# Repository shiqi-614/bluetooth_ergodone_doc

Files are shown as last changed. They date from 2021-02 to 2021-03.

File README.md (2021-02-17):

# bluetooth ergodone doc

系列文章, 分享如何制作一个蓝牙版的ergodone

由于众所周知的原因, github上的图片不能访问, 可以把本项目下载到本地, 然后用markdown编辑器打开.

或者移步我在CSDN上的博客[地址](https://blog.csdn.net/shiqi_614/article/details/113758502)

改造流程参考教程:
* [为什么要自己做一把蓝牙机械键盘](./chapter1_cn.md)
* [用到的东西](./chapter2_cn.md)
* [制作左手](./chapter3_cn.md)
* [设置左右手蓝牙BLE](./chapter4_cn.md)
* [制作右手](./chapter5_cn.md)
* [轴体焊接及供电模块](./chapter6_cn.md)
* [后记](./chapter_tips_cn.md)

代码地址: [bluetooth_ergodone](https://github.com/shiqi-614/bluetooth_ergodone)

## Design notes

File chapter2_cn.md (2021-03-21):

# 用到的东西

## 系列文章列表
* [为什么要自己做一把蓝牙机械键盘](./chapter1_cn.md)
* [用到的东西](./chapter2_cn.md)
* [制作左手](./chapter3_cn.md)
* [设置左右手蓝牙BLE](./chapter4_cn.md)
* [制作右手](./chapter5_cn.md)
* [轴体焊接及供电模块](./chapter6_cn.md)
* [后记](./chapter_tips_cn.md)

## 硬件相关
#### 焊接工具
* **电烙铁**
* **烙铁架**
* **高温海绵**: 在水中充分浸泡, 挤干后放置在烙铁架
* **焊锡**
* **松香**: 助焊剂, 焊出来的点比较亮, 不容易虚焊
* **吸锡枪**: 如果焊坏了, 将焊点的焊锡吸走, 重新焊
* **电工黑胶带**: 有时候用胶带辅助固定比较好焊
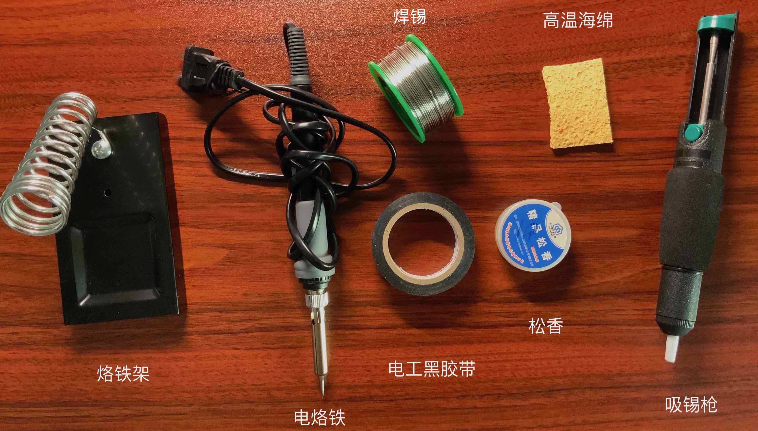
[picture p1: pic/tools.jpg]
焊接工具


#### PCB板等
* **PCB板**: github上有PCB图纸[ErgoDone](https://github.com/shiqi-614/ErgoDone), 需要找淘宝店打印, 用软件[kicad](https://kicad.org/)打开具体的文件查看PCB图纸
* **1n4148二极管 * 76**: 规定电路板上电流的走向, 避免按一个键, 电流走到其他路径, 导致其他按键也认为被触发了, 可以多买些.
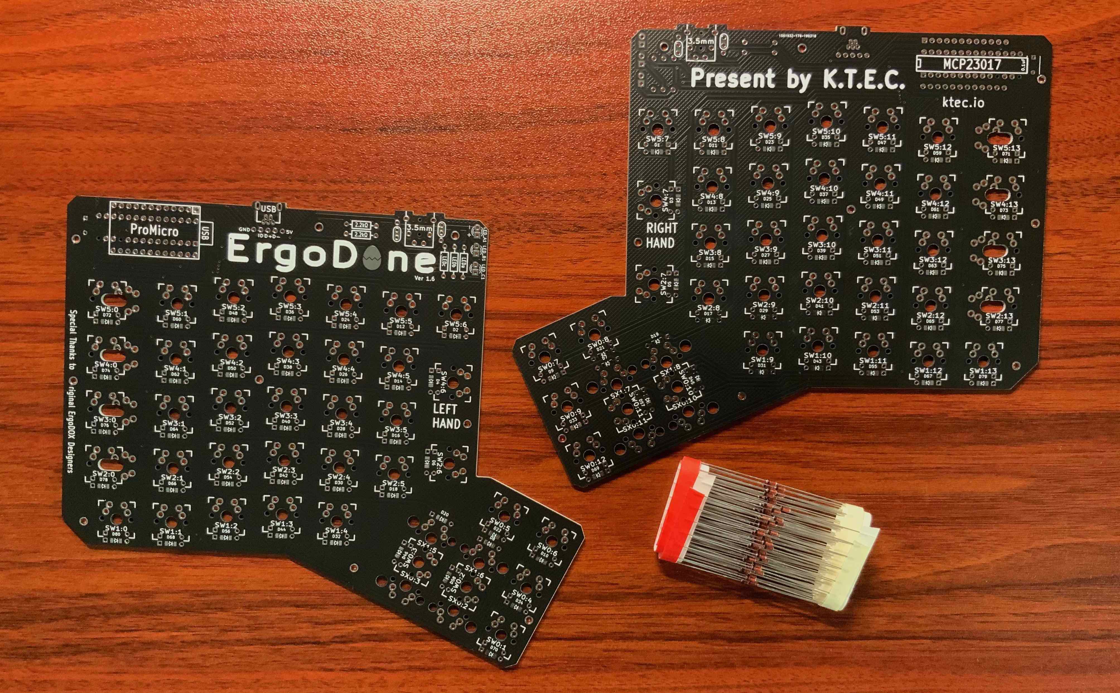
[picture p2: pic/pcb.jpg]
PCB


### 键盘轴体键帽等
* **喜欢的轴休 * 76**: 比如我这里大部分是茶轴, 几个是青轴
* **键帽**: 4个2U的, 12个1.5U的, 60个1U的, 这里我用的白色无刻的
* **PCB卫星轴2U * 4**: 在焊轴前, 安装和调试好卫星轴
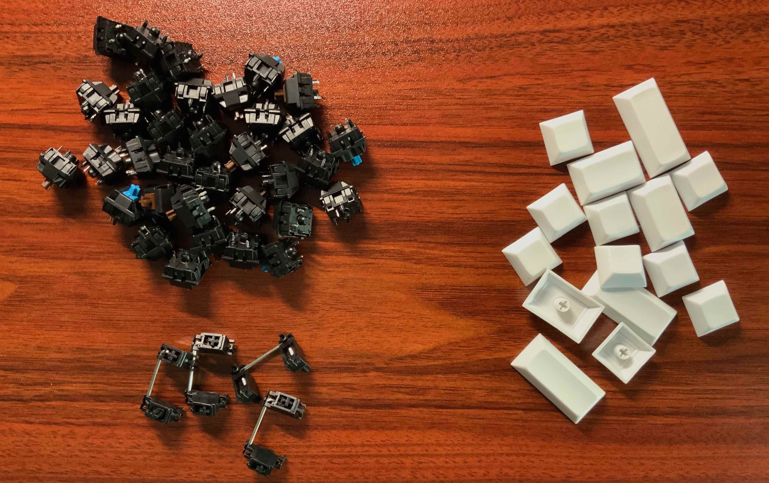
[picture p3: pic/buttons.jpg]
轴体等


### 芯片等
* **Arduino Pro Micro * 2**: 左右手各一块, 主控芯片, 其他名字有min leonardo, ATMEGA32u4. 从淘宝上买, 一般会送直脚排针
* **MCP23017**: IO扩展模块，因为右手需要接入多块芯片或模组及处理键盘事件, 导致IO口不够, 所以用这个来扩展IO口. 使用说明[datasheet](https://pdf1.alldatasheetcn.com/datasheet-pdf/download/195324/MICROCHIP/MCP23017.html), 需要配合2.2K欧的电阻使用.
* **2.2K欧色环电阻 * 2**: 配合MCP23017使用
* **HM-10带底板 * 2**: 左手的Arduino Pro Micro将识别出来的按键事件发送给左手的HM-10, 然后左手的HM-10通过蓝牙将事件发送给右手的HM-10, 右手的HM-10发送给Arduino Pro Micro, 然后发送Bluetooth HID模组
* **Bluetooth HID模组**: HC-03带底板, 这里用的HC-03刷上RN42的固件, 用来给电脑发送鼠标键盘事件, 可以自己制作, 参考[教程](https://mitxela.com/projects/bluetooth_hid_gamepad), 也可以直接从淘宝上买
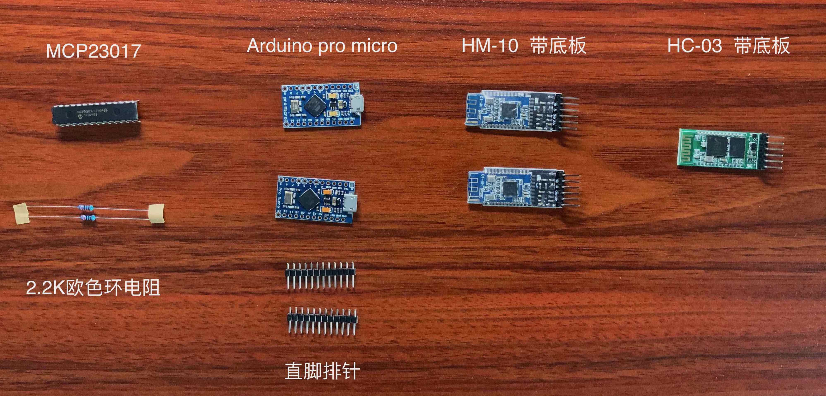
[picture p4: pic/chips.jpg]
芯片等


### 电源模块相关
* **锂电池 * 2**: 用来给芯片供电, 厚度不要超过6mm, 这里我选了一个厚度6mm, 宽度6mm, 长度10mm, 5000mAh, 并且带保护板的电池
* **TP4056充电模块 * 2**: 用来给锂电池充电, 我选的type c口的
* **拨动开关 * 2**: SS12D10, 用来控制电源的开关
* **易拉胶 * 2**: 用来固定电池, 使用易拉胶可以方便以后更换电池, 这里我用是苹果6P的易拉胶
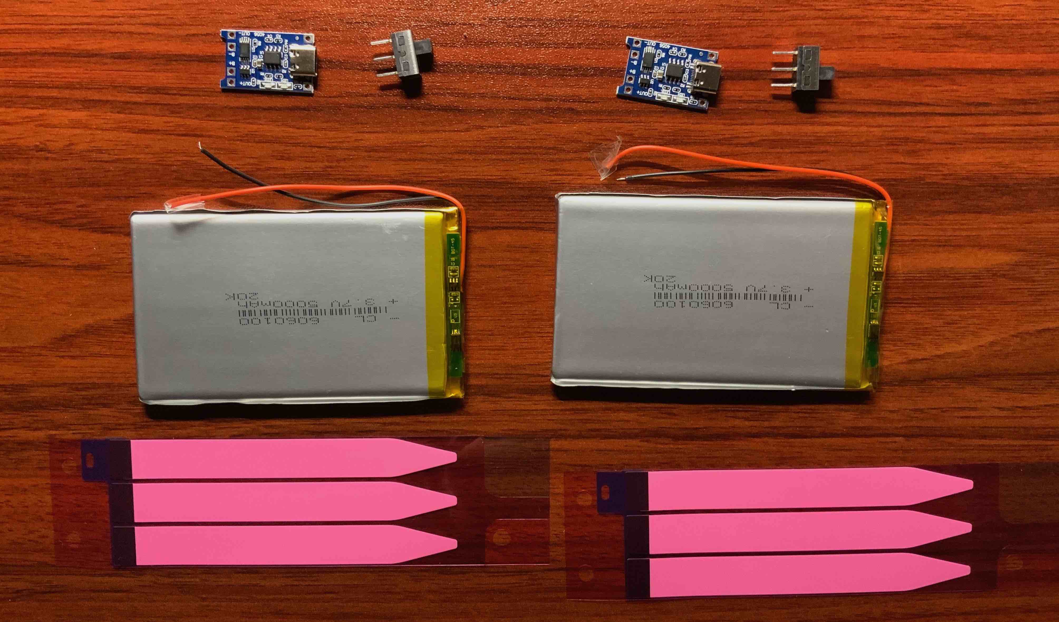
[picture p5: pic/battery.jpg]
电源模块


### 外壳等
* **亚克力外壳**: 我在键盘上加了摇杆, 这是可选的, 如果不想要摇杆, 可以使用这个[不带摇杆的CAD图纸](./cad/Bluetooth_Ergodone_without_joystick.dwg),  如果你也想加上摇杆, 用这个[带摇杆的CAD图纸](./cad/Bluetooth_ErgoDone_with_joystick.dwg), 材料是亚克力, 同样需要找淘宝店加工, 费用大概在120元左右. 可以用AutoCAD打开并编辑这样的文件, 新用户有30天试用, 还是比较方便的. 把膜撕了之后, 就是右手透明的样子, 很好看.
* **M2双通铜柱19MM * 14**: 用来固定外壳
* **M2螺丝8MM * 28**: 用来固定外壳
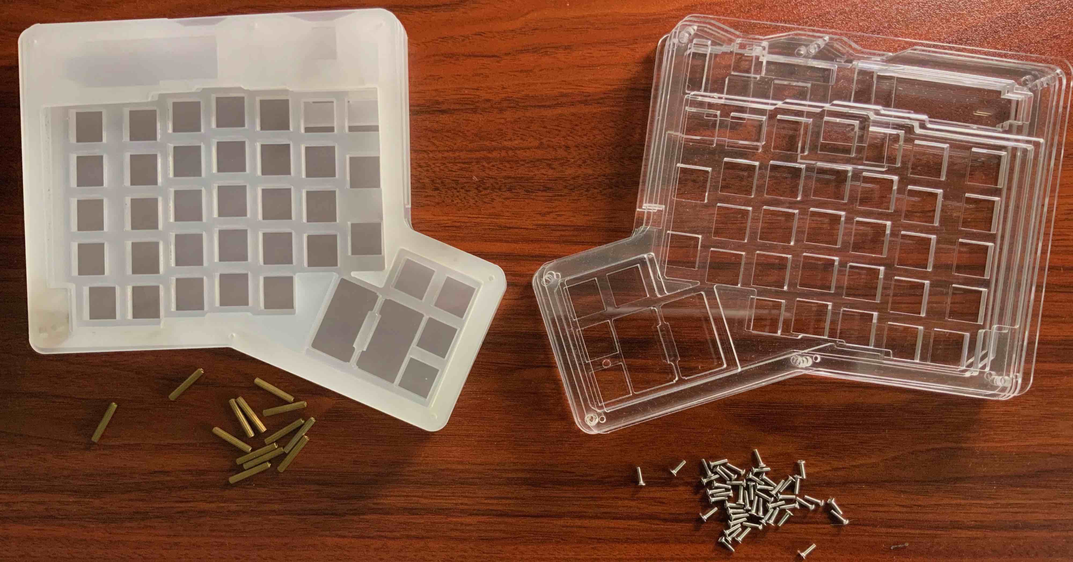
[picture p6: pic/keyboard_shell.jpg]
外壳等


####  连接线
* **弯脚排针**: 为了避免直接用跳线焊接到芯片或者模组的引脚上, 先焊接上排针, 然后用杜邦线连接, 方便以后更换芯片, 如果觉得不牢靠, 可以用黑胶布再固定一下
* **母对母杜邦线**: 用来连接芯片模组和PCB等. 我用到了10CM, 15CM 20CM三种长度的. 当然也可以直接用跳线焊死, 就不用上面的弯脚排针了. 可以买一个公对公的杜邦线, 在没有焊上轴之前, 当成导线测试二极管焊得对不对.
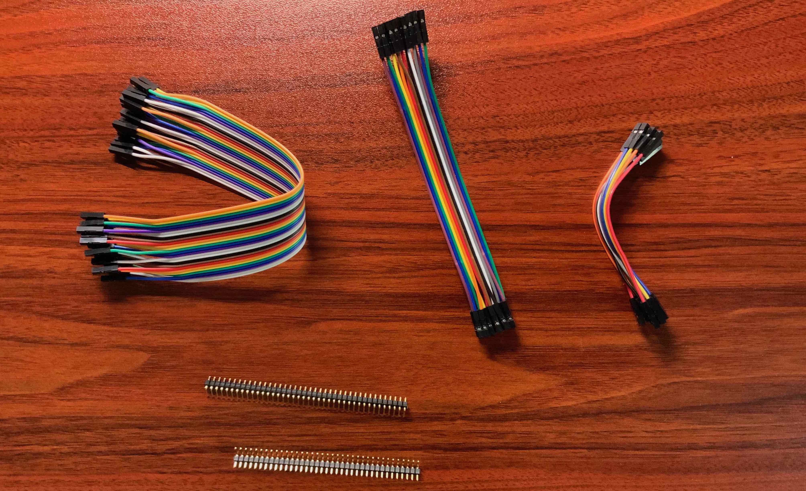
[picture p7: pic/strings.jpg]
连接线


### 其他
* **USB转Micro USB * 2**: 在测试的时候, 同时给两块Arduino Pro Micro供电需要用到, 也用来给芯片烧录程序, 所以要买那种支持数据传输的.
* **330欧色环电阻 * 3**: 避免电流过大烧坏LED灯.
* **234 LED方灯 * 3**: 放在键盘上, 可以用来提示CAPS_LOCK, 或者自定义提醒键盘布局变化.
* **纳米双面胶**: 用来固定芯片或者模组, 粘在外壳上

### 可选
* **摇杆**: 用来控制鼠标, 类似于thinkpad上的小红点
* **小红帽**: 因为上面的摇杆自带的摇杆帽太高了, 使用起来不舒服,所以用thinkpad小红点上的小红帽替代, 也可以先试试原装的蘑菇帽, 觉得不行了, 再换成小红帽试试(可惜没有矮点的蘑菇帽, 原装的蘑菇帽手感非常 好), 不是成熟的方案, 我自己也不满意, 如果有更好的方案, 请指教.
* **502胶水**: 因为小红帽和摇杆不匹配, 塞了点东西, 用脱水粘上
* **隐形笔记本支架**: 让键盘有一个比较舒服的角度
* **鼠标垫**: 因为加了一块电池的键盘太厚了, 所以加了鼠标垫拖着手, 一手一块不够厚, 所以一手两块
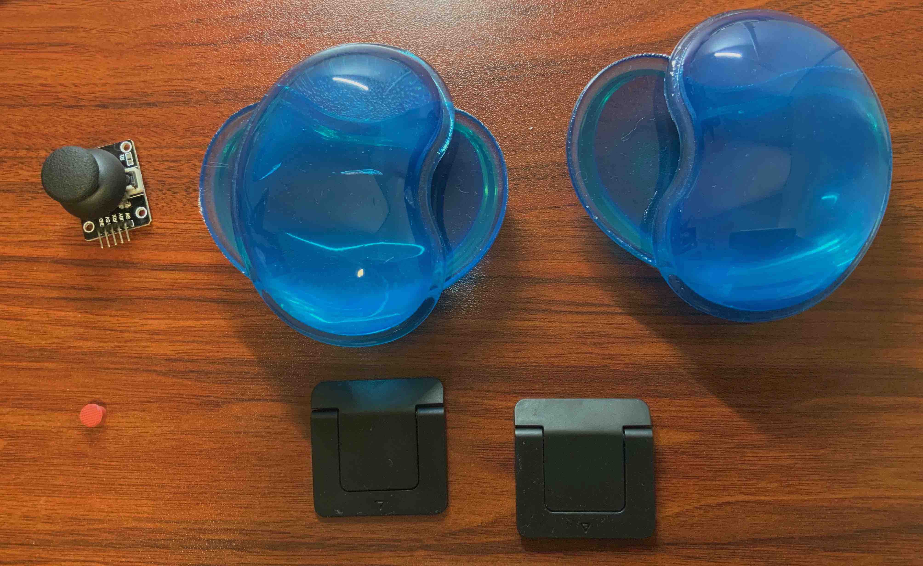
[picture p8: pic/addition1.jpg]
addition1

* **阳极铝定位板**: 我在使用中摔过一次, 定位板碎了, 因为定位板是和PCB板焊在一起的, 更换起来很麻烦,  所以这次用了金属材料, 阳极氧化铝, 如果你也需要, 可以用这个[定位板的图纸](./cad/positioning_plate.dwg), 其他不变.
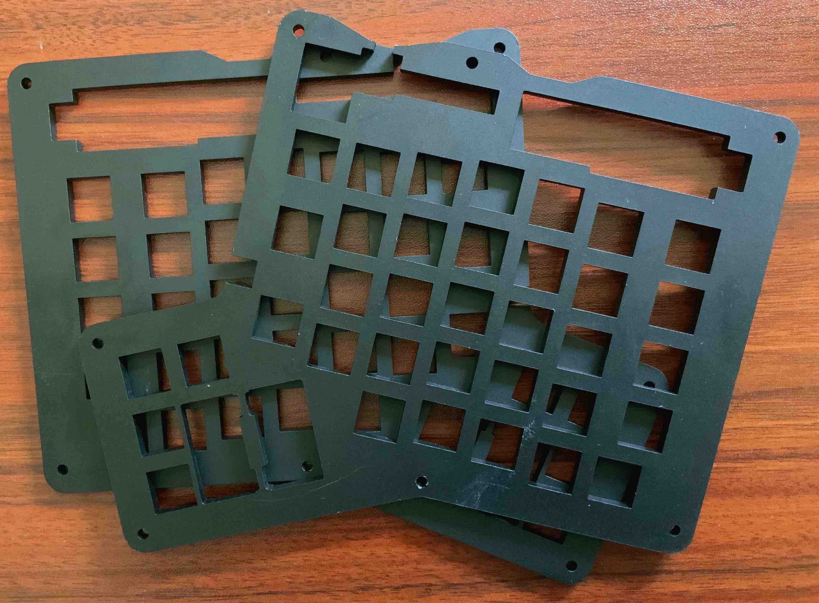
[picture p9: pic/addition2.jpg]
addition2


## 软件相关
使用了[Arduino IDE](https://www.arduino.cc/en/software), 基于[arduino_tmk_keyboard](https://github.com/bgould/arduino_tmk_keyboard).

代码使用方法是: 从Release里下载[bluetooth_ergodone.zip](https://github.com/shiqi-614/bluetooth_ergodone/releases/download/1.0/bluetooth_ergodone.zip), 在Arduino IDE里, 通过"项目" -> "加载库" -> "添加.zip库", 把本项目导入.

导入完成后, 还需要
1. **选择正确的示例程序**: 在Arduino IDE里, 通过"文件" -> "示例", 找到本项目名, 然后打开左手或者右手的示例程序,
2. **选择正确的开发板**: 在Arduino IDE里, 通过"工具" -> "开发板"里选择Arduino Leonardo,
3. **选择正确的端口**: 当电脑的USB连接到主控芯片(Arduino Pro Micro)后, 在"工具"->"端口"里会出现一个新的端口, 选择这个端口.

然后点Arduino IDE左上角的"上传"按钮, 就可以将代码上传到主控芯片里了.

在右手的示例程序里[right_hand.ino](https://github.com/shiqi-614/bluetooth_ergodone/blob/master/examples/right_hand/right_hand.ino), 可以通过ERGODONE_KEYMAP去定义自己的键盘布局, 支持多个键盘布局的切换, 比如我定义了三层, 第三层是鼠标的操作. 还可以自己定义一些宏操作, 比如在第二层里自定义了FN6, 按下这个键, 就会输出Hello, World. 更多玩法, 参考[tmk keymap](https://github.com/tmk/tmk_keyboard/blob/master/tmk_core/doc/keymap.md).

并且也是在右手的程序里[right_hand.ino](https://github.com/shiqi-614/bluetooth_ergodone/blob/master/examples/right_hand/right_hand.ino)通过各种hook函数控制LED灯.

我自己定义键盘布局里, 左手CAPS_LOCK按键的位置被我换了, 按成按着的时候, 会切换到第三层, 第三层是鼠标操作, 在第三层, 按下HJKL会移动鼠标. 原来Z键的位置, 被我换成按下切换到第二层, 这时候HJKL就变成方向键, 原来的Z向右移了一位.

# 最后的成品
### 正面
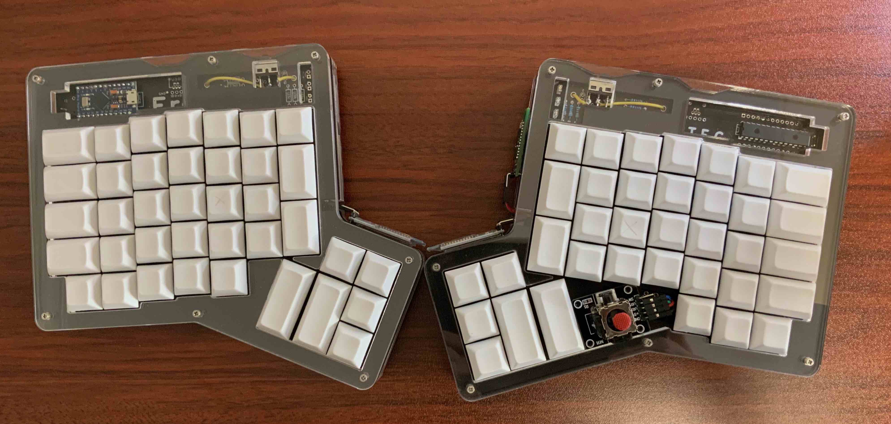
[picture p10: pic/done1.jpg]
done1


### 背面
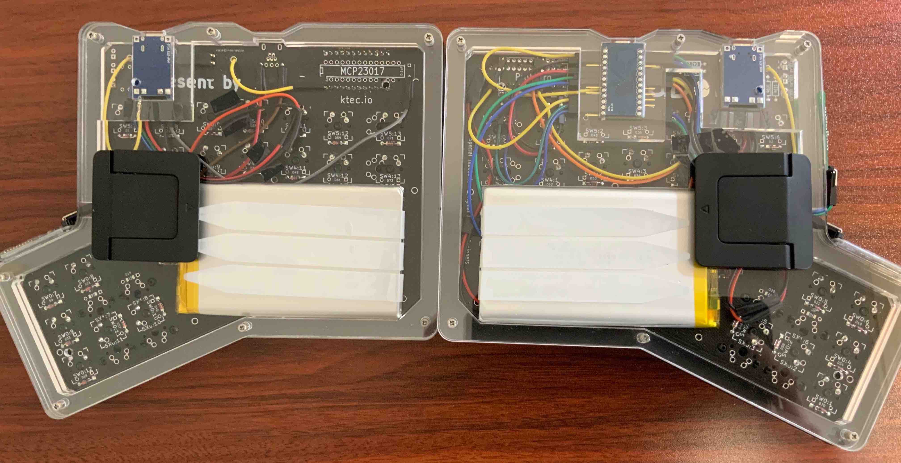
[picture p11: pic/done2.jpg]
done2


### 侧面
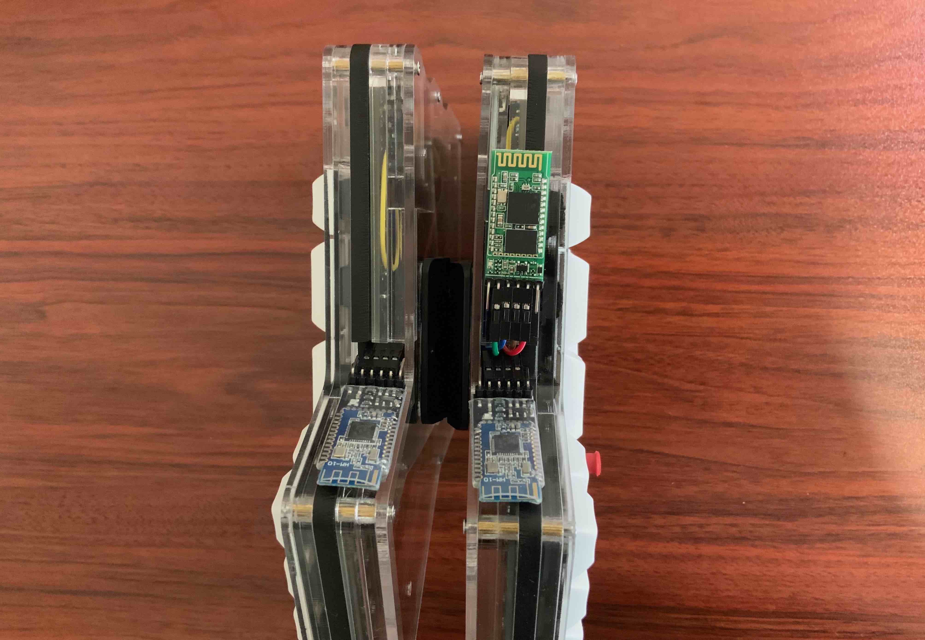
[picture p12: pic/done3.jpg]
done3


### 用起来的样子 
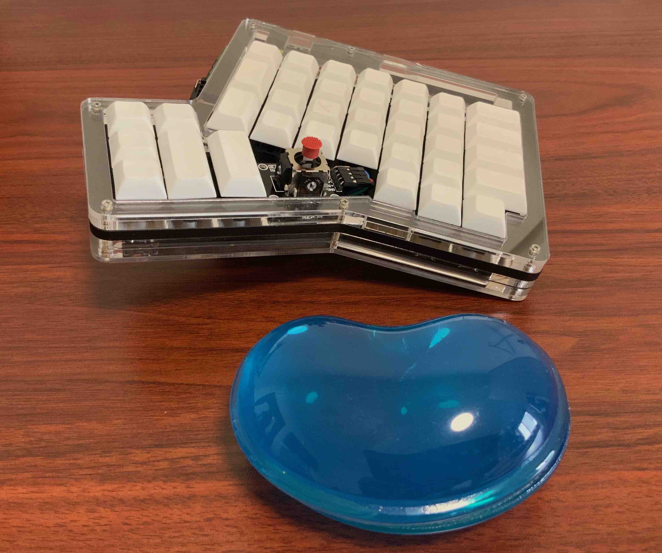
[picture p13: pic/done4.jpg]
done4


续航测试, 右手大概在360个小时之后, 开始出现连接不稳定, 左手这时候还能继续用, 左手没有继续测试下去.

测试过的能连接上的设备包括Mac电脑, windows电脑, ipad, iphone, 小米6.

延迟测试, 不会有明显的延迟, 尝试使用程序测试, 左手某个按键按下, 从Arudino打印的时间, 对比电脑上python监测程序打印出来的时间, 三四十毫秒到八九十毫秒都有. 不过应该是大概二十毫秒, 考虑到蓝牙传输的延迟(七点五毫秒发送一次按键事件, 这里乘以二, 因为有两个), 程序里去抖动延迟五毫秒(由于机械轴触发的原理是两个弹片互相接触, 机械接触的话难以避免碰撞, 又因为程序检测的速度极快, 所以这段极小的碰撞时间内程序检测到的状态是不稳定的, 会被认为是按下松开按键多次). 网上有人用拍视频的方式计算, 用视频里按下按键的帧数到屏幕显示出来的帧数, 计算出对应的时间. 比较麻烦, 放弃.

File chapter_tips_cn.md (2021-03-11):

# 后记

## 系列文章列表
* [为什么要自己做一把蓝牙机械键盘](./chapter1_cn.md)
* [用到的东西](./chapter2_cn.md)
* [制作左手](./chapter3_cn.md)
* [设置左右手蓝牙BLE](./chapter4_cn.md)
* [制作右手](./chapter5_cn.md)
* [轴体焊接及供电模块](./chapter6_cn.md)
* [后记](./chapter_tips_cn.md)

### 一些想法
* 我觉得外壳的分层的设计挺好的, 可以单独对某些层做特别的定制, 除了成本方面的考虑之外, 比如对右手有装摇杆需求的, 就可以仅向右手上面两层做一些修改, 使得摇杆能够放下. 那么可以更进一步, 除了PCB板和定位板是焊死的 (这块拆起来比较麻烦, 需要用吸锡器清理38个焊点), 在现在的设计里, 所有的连线都没有焊死, 用的是杜邦线进行连接, 意味着如果你想用其他的充电模块, 你可以把对应充电模块的那一层, 包括芯片模组和外壳整体替换掉, 而其他层保持不变, 这为以后维护升级提供了许多便利.
* 一开始我想着, 可以让左右手互相通信, 但是后来放弃了这个想法, 沿用了类似于HM-10的主从模式, 因为如果左右手需要通信才可以完成一些事件, 意味着单独右手不能成为一个独立的键盘, 需要和某个左手绑定, 这我认为是没有必要的, 并且如果遵守蓝牙BLE的协议, 左手其实可以是其他的设备, 并不一定要是键盘, 可以玩出更多花样.
* Bluetooth HID模组本来想用RN42的, 但是成本太高了, 裸片都要100多块(我焊不上去, 放弃), 带上底板了直接上300多块钱了, 而淘宝上用HC-03刷RN42固件的, 加上运费也只需要30多, 两者价格相差10倍, 试错成本太高了, 导致放弃了这个方案. 
* Bluetooth HID模组后来还尝试过ESP-32, 这块芯片集成了蓝牙和无线, 通过阅读了蓝牙HID协议, 把github上用ESP-32分别操作键盘和鼠标的合在一起, 但是ESP-32太娇贵了(一块50多, 官方淘宝店运费23), 我在续航测试中, 测到没电, 再供电时, 蓝牙就无法连接了, 再加上其他问题(体积太大, 续航等), 导致我也放弃了这个方案. 所以Bluetooth HID这块, 用的现在的方案. 这个方案不能对代码进行一些定制, 导致有些功能, 比如鼠标滚轮左右滚, 如同罗技K380那样, 一键切换多台设备, 不能实现.
* 代码方面, 固件QMK比TMK功能更强大, 并且也更流行一些, 但是刷QMK的固件更麻烦一些, 需要额外的知识, 而用Arduino IDE对小白来说更友好, 在界面上点一下"上传"就搞定了(其实这个过程有把代码输出成HEX格式的文件, 再烧录到芯片里), 并且在网上找到了将TMK移植到Arduino上的项目(即arduino_tmk_keyboard), 所以最终采用了TMK, 因为arduino_tmk_keyboard里使用的TMK版本有点老, 有挺多bug, 所以最后折腾了一阵, 升级到当前最新版的TMK, 除了升级, 适配新的硬件, 还在主程序里增加了一些hook的接口, 我是用hook的接口还实现led的控制.
* 现在并没有休眠功能, 因为正常用下来, 右手一个月左右充一次电, 左手时间更长, 对我来说, 是能接受的.
* 想实现像罗技K380的一键切换多个设备的功能 (比如你有电脑和IPAD, 上班的时候键盘上的蓝牙连接的是电脑, 下班之后, 按下键盘上的一个按键, 键盘上的蓝牙就连接上IPAD的了, 明天上班了, 按下另一个按键上的蓝牙就连接上电脑了), 这得对蓝牙HID模组的固件进行定制, 找到开源项目[cc254x-hidKbdM](https://github.com/rampadc/cc254x-hidKbdM), 对应的烧录的教程在[这里](https://www.cyqsd.cn/8498.html), 完成这个功能需要大量时间, 有时间再弄.

### 踩过的坑
* 有些micro USB线仅支持充电, 用这种线, 是识别不出芯片的, 要买那种还支持数据传输的.
* 淘宝上有许多HM10, 最好去官网的淘宝店买, 因为需要配置主从模式, 其他淘宝店上的命令和官网有点不一样, 有时候弄不成功, 淘宝客服找了技术支持, 把我自己的linux系统装了windows系统, 买了USB转TTL的线从windows上连接, 折腾好一阵, 还是不行, 所以找官网的淘宝店买最好, 不过官网的淘宝店运费真的贵.
* HM-10左右手虽然连接上了, 但是左手给右手发的数据老是接不到, 后来把右手的HM-10上的TX和RX与Arduino Pro Micro的RX和TX连接, 才能收到数据. 其他引脚是用的模拟串口通信, Arduini Pro Micro上的TX和RX引脚是硬件支持串口通信的. 后来并没有用官方淘宝店的HM-10做实验, 也不知道是哪里的问题.
* 用过ESP32-DevKitC作为蓝牙HID ,  我做续航测试的时候, 电池电量消耗完之后, ESP32的蓝牙功能就出问题了, 然后因为ESP32上面的软件也是我写的, 虽然是蓝牙4.0, 不过没有休眠之类的功能, 导致续航比较低(只有50个小时), 然后ESP32-DevKitC也比较大, 之前从非官网的淘宝店买, 还出现过, 引脚标错的情况, 折腾了许久.
* 用过黑莓的轨迹球去控制鼠标, 这个模组很小, 不过不能同时识别两个方向, 所以往右上移动, 只能先往右移动, 再往上移动, 所以体验不是很好, 虽然我用软件尝试去解决, 但是效果也不好.
* 单独找了淘宝店做阳极铝的定位板, 但是在开关位置, 精度有点问题, 用的开关宽是12.7MM, 长是13.2(不包括拨动的那一部分), 图纸里标了宽12.77MM, 长度是13.4MM, 但是楞是卡不进去, 最后使用把定位板对应的位置刮了刮, 把开关的脚剪掉一部分, 才能用力锤进去的, 原来亚克力的版本就能顺利卡进去.
* 用阳极铝定位板, 如果PCB上的二极管的焊点太突出了, 会导致电流走到定位板上, 导致一些奇怪的现象, 所以这时候要用黑胶布把焊点盖一下.

我在B站上上传了一个之前0.1版本的制作过程的视频, https://www.bilibili.com/video/BV1qv411y7vA, 不知道会有多少人看到这里, 如果你看到了这里, 可以去给这个视频点个赞或者投个币, 一起看看结果.

### 参考资料

#### B站：
* 10天学会51单片机—郭天祥
* CAD2018新手快速入门精品课

#### 文档书籍：
* 从零开始学单片机技术
* Arduino基础入门
* 普及版ErgoDox——ErgoDone二狗蛋人体工学
* 正式版Ergodone二狗蛋教程(群友分享)
* datasheet of ESP32
* datasheet of MCP23017
* datasheet of HM10

#### github:
* bgould/arduino_tmk_keyboard
* tmk/tmk_keyboard
* LSChyi/BlueErgo_Protype
* T-vK/ESP32-BLE-Keyboard
* T-vK/ESP32-BLE-Mouse
* ktec-hq/ErgoDone
* LSChyi/blackberry-mini-trackball

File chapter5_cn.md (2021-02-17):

# 制作右手

## 系列文章列表
* [为什么要自己做一把蓝牙机械键盘](./chapter1_cn.md)
* [用到的东西](./chapter2_cn.md)
* [制作左手](./chapter3_cn.md)
* [设置左右手蓝牙BLE](./chapter4_cn.md)
* [制作右手](./chapter5_cn.md)
* [轴体焊接及供电模块](./chapter6_cn.md)
* [后记](./chapter_tips_cn.md)

在前面的章节里, 我们完成了左手的焊接, BLE的设置, 接下来开始制作右手, 右手会负责接受左手键盘发过来的信息, 摇杆信号的变化, 右手键盘的事件, 控制LED灯, 还负责跟电脑打交道. 可以用下图表示整个键盘各种模块之间的关系.
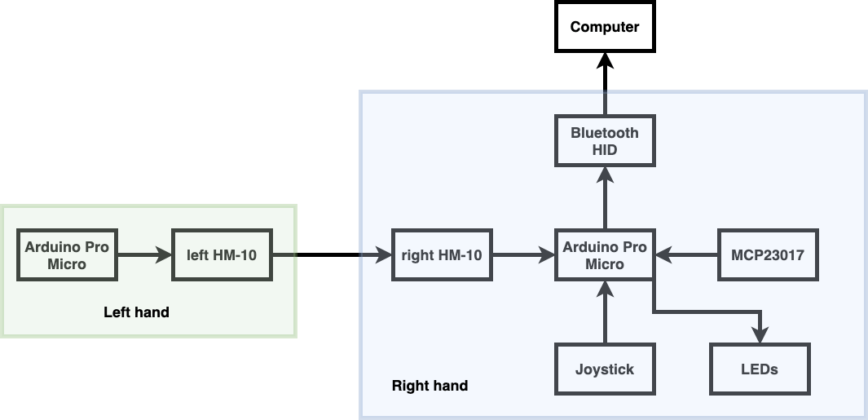
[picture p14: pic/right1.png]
right1


为什么要加一个MCP23017呢?

可以从上图看到, 右手的Arduino Pro Micro要负责的事情很多, 但是IO引脚数目有限, 如果像左手那样, 光监测键盘事件就把IO引脚基本占用完了, 所以用MCP23017去扩展IO引脚, 这个模组可以用2根IO引脚扩展出16根IO引脚, PCB上也给MCP23017预留了位置. 至于原理是什么, 有兴趣可以找一下MCP23017的datasheet, 里面介绍得很详细.

拿出一张PCB板, MCP23017, 按照下图放好, 特别要注意放的方向, 然后焊接上.
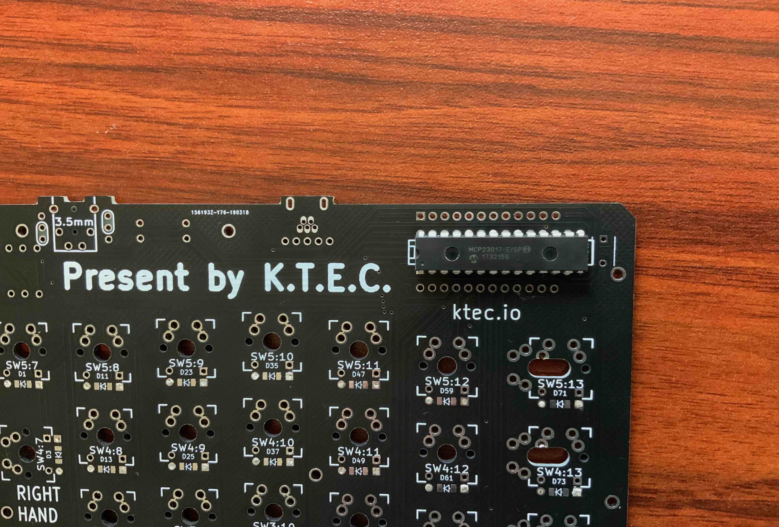
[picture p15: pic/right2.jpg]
right2


接下来把对应位置的电阻也焊接上. 位置1焊接2个2.2K殴的电阻, 位置2焊接3个330欧电阻, 这时候LED灯先不着急焊, 因为如果LED灯方向焊反了, 灯就亮不起来了.
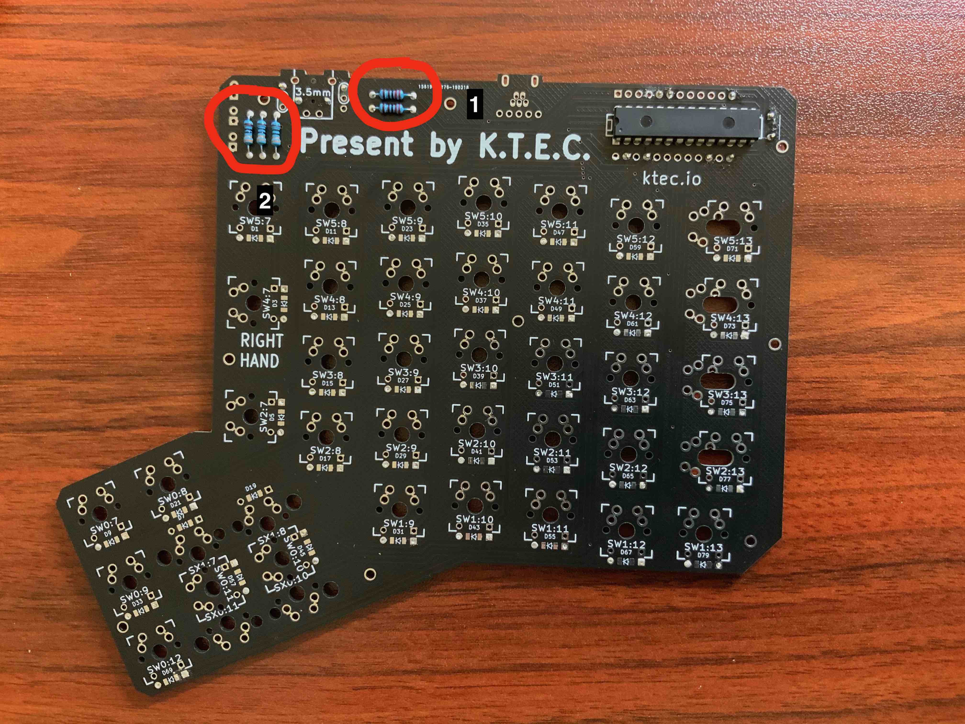
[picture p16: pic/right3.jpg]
right3


然后翻到反面, 把二极管也焊接上, 并且在下面的几个位置也用之前教的方法, 焊上弯脚排针.
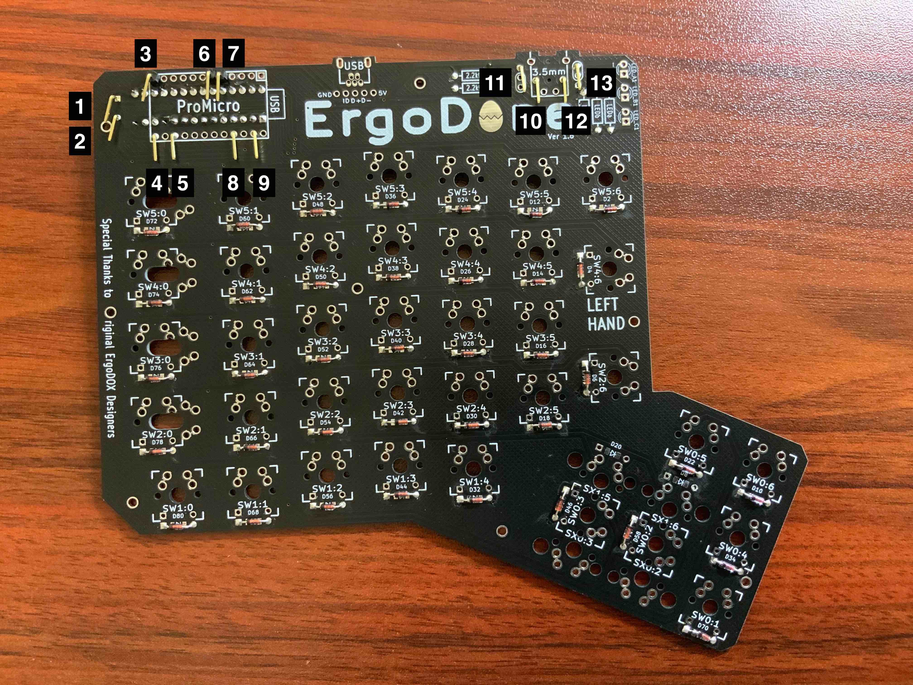
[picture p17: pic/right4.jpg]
right4

可以先把位置3456789连接上, 先测试LED和MCP23017是否正常工作,  完整的连接对应关系如下:

* 1 (VCC)    -> Joystick pin 5V
* 2 (GND)    -> Joystick pin GND
* 3 (LED A)  -> Arduino Pro Micro pin 15
* 4 (LED B)  -> Arduino Pro Micro pin 14
* 5 (LED C)  -> Arduino Pro Micro pin 16
* 6 (SCLM 与MCP23017通信的)  -> Arduino Pro Micro pin 3
* 7 (SDAM 与MCP23017通信的)  -> Arduino Pro Micro pin 2
* 8 (VCC)    -> Arduino Pro Micro pin VCC
* 9 (GND)    -> Arduino Pro Micro pin GND
* 10 (VCC)   -> HM-10 pin VCC
* 11 (GND)   -> HM-10 pin GND
* 12 (VCC)   -> Bluetooth HID pin VCC
* 13 (GND)   -> Bluetooth HID pin GND

另外, 还需要将HM-10, Bluetooth HID, Joystick数据传输的引脚跟Arduino Pro Micro相连, 具体如下:
* HM-10 pin TXD         -> Arduino Pro Micro pin RXD
* HM-10 pin RXD         -> Arduino Pro Micro pin TXD
* Bluetooth HID pin TXD -> Arduino Pro Micro pin 8
* Bluetooth HID pin RXD -> Arduino Pro Micro pin 9
* Joystick pin URX      -> Arduino Pro Micro pin A3
* Joystick pin URY      -> Arduino Pro Micro pin A2
* Joystick pin SW       -> Arduino Pro Micro pin A1

拿出之前焊好的右手的Arduino Pro Micro, 把位置3456789连接好之后, 打开示例, 找到本项目里的"test_mcp23017_led", 上传到Arduino Pro Micro里, 然后我们可以选三个自己觉得好看的LED灯, 放到对应的位置, 看是否能亮起来. 下图所示, 我选了黄色, 蓝色和绿色, 并且LED灯能正确亮起来, 这时候就可以放心地把LED焊上去.
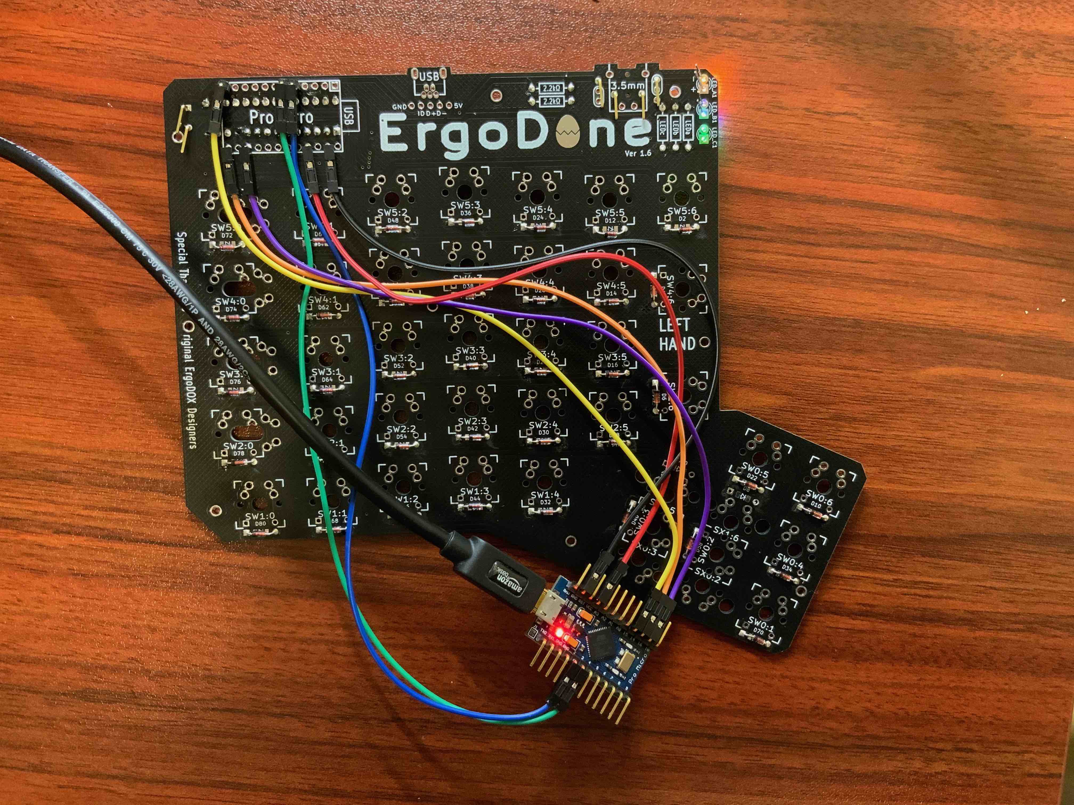
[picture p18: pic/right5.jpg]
right5


这时候, 可以模拟下右手PCB上按键按下的事件. 如果能打印出对应的行和状态(这里是二进制表示), 那么MCP23017的功能也验证成功了.
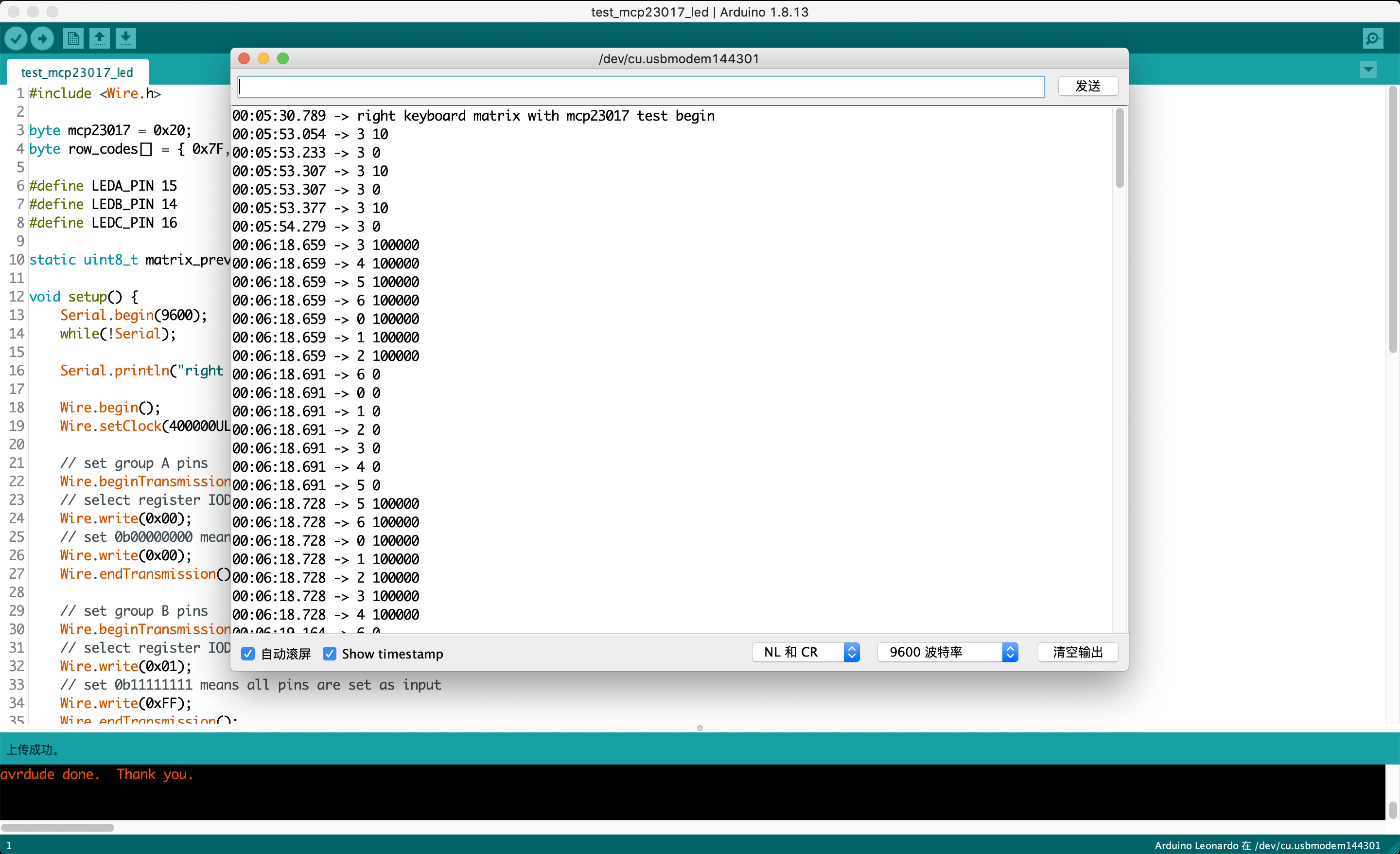
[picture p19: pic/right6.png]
right6


那么现在, 除去充电供电模块外壳等, 你手上已经有一个完整的键盘了, 按照上面的列表, 把所有的连线通过杜邦线连接起来, 并且给左手的Arduino Pro Micro也上电, 这就完成了一个具备所有功能的键盘.

强烈建议这时候去试一下整个键盘的功能, 是否正常, 所有的按键能否正常响应, 摇杆能否正常工作, 之后把外壳等加上去, 检查出问题, 再修复就麻烦一些了.
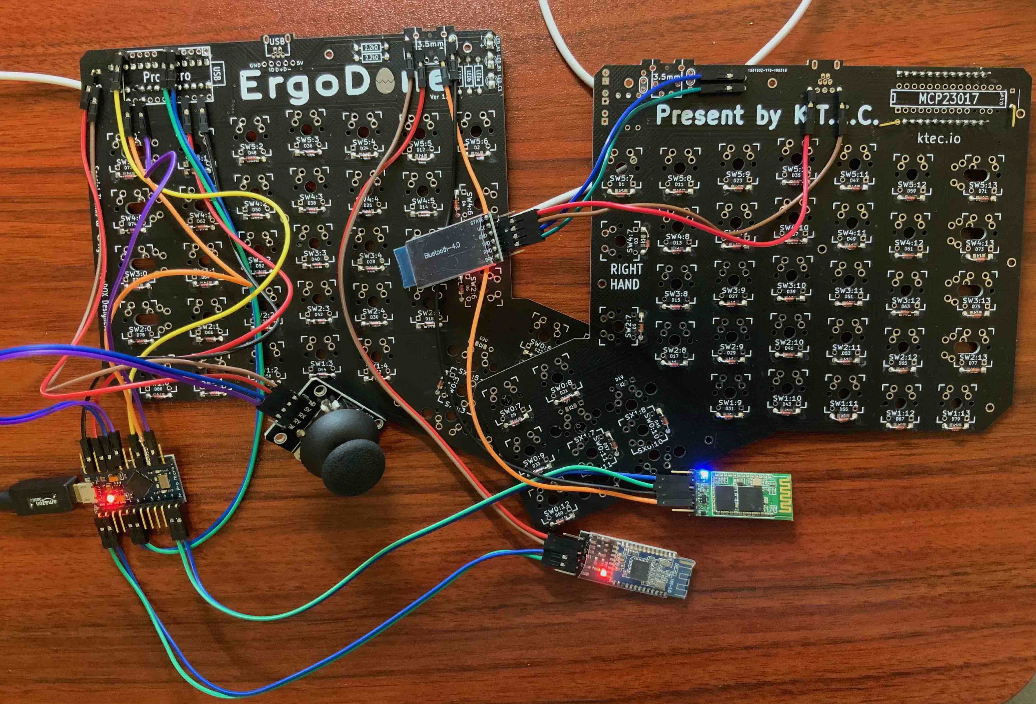
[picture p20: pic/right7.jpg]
right7


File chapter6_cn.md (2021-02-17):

# 轴体焊接及制作供电模块

## 系列文章列表
* [为什么要自己做一把蓝牙机械键盘](./chapter1_cn.md)
* [用到的东西](./chapter2_cn.md)
* [制作左手](./chapter3_cn.md)
* [设置左右手蓝牙BLE](./chapter4_cn.md)
* [制作右手](./chapter5_cn.md)
* [轴体焊接及供电模块](./chapter6_cn.md)
* [后记](./chapter_tips_cn.md)

在前面的章节里, 硬件和软件都验证完成了, 接下来就可以把轴体焊接上去, 把供电模块加上去了.

如果你使用的时阳极铝定位板, 在焊轴之前, 最好把下面的二极管焊接点, 用黑胶布粘上. 避免阳极铝导电, 而造成的奇怪的现象.
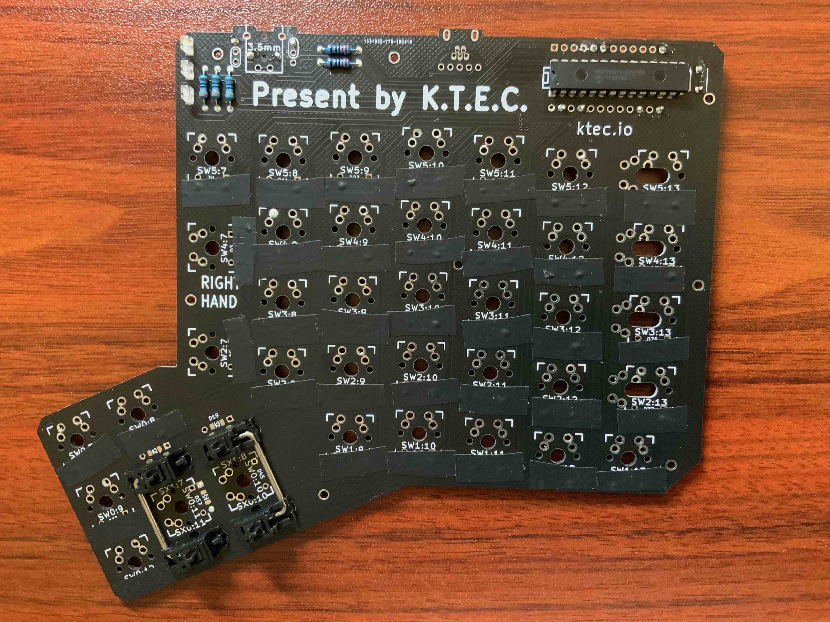
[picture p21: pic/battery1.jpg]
batter1


在焊轴之前, 先把卫星轴安上去, 调试一下, 因为如果没有安装好, 会很影响手感.
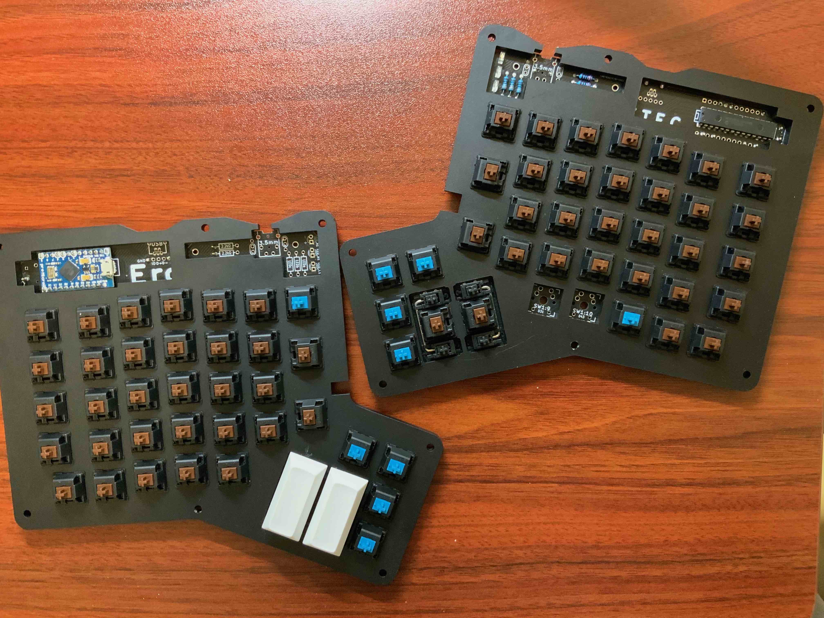
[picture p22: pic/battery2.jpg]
batter2


然后把轴焊上去.
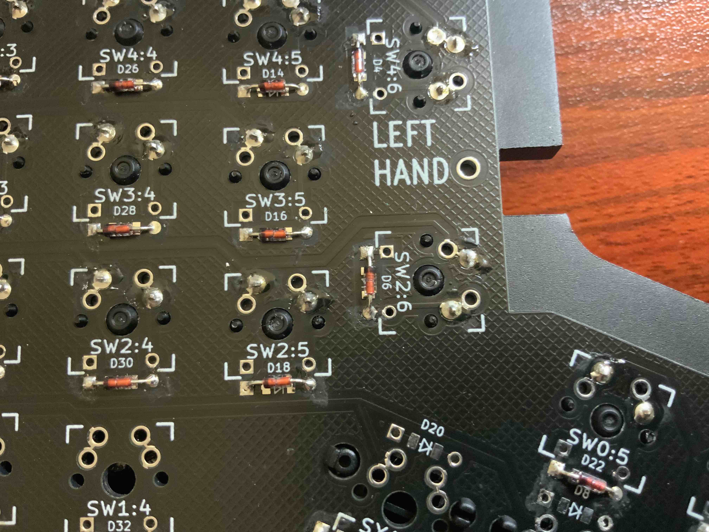
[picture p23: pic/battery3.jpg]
batter3


然后拿出一块TP4056充电模块, 拿出放充电模块的外壳和一个只有边框的外壳. 按照下图的方式放在一起, 然后同样用弯脚排针放进充电模板的引脚里, 用胶布固定在外壳上.
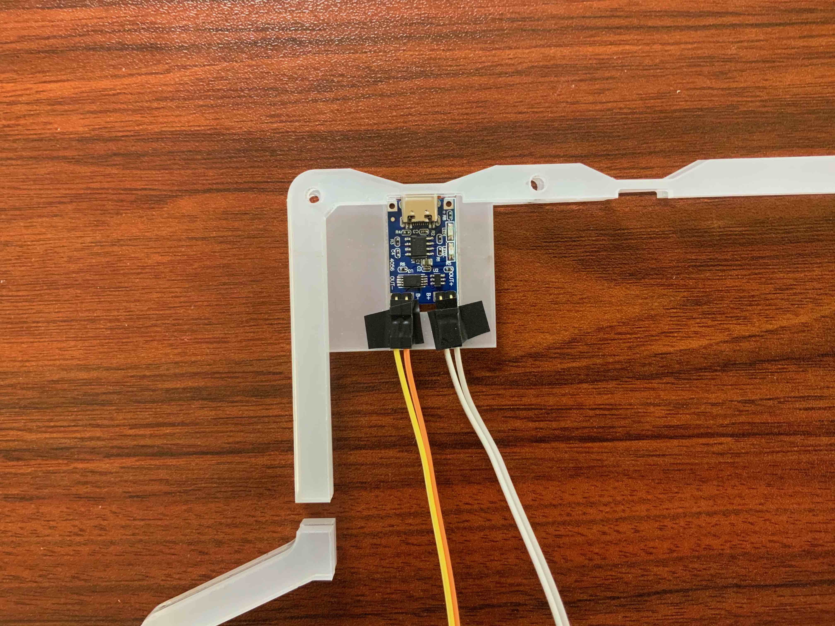
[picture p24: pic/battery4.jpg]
batter4


翻过来, 把充电模块上的弯脚排针焊上. 只有边框的外壳, 是放在PCB板和电池之间, 提供一些空间, 避免直接接触, 也能卡住充电模板, 避免掉下来, 如果不放心, 也可以用黑胶布多固定一下. 焊好之后, 如下图.
batter5

接下来处理锂电池, 拿出一个锂电池, 把它跟杜邦线接在一起, 具体做法是把杜邦线切成两半, 然后把塑料外壳去掉一些, 我是正面划一刀, 背面划一刀, 然后剥开, 锂电池对应红黑线的地方也做相同的处理, 然后把它们缠在一起, 用焊锡加固一下, 再用黑胶布包一下.
batter6
 
拿出一个拨动开关, 同样是把杜邦线一头的塑料外壳去掉一些, 缠到开关相邻的的脚上, 用焊锡固定. 右手的开关的杜邦线弄长一些, 因为右手键盘里的线太多了, 理线比较有发挥空间.
batter7

因为供电模块两手各一组, 所以把两组都处理完.
batter8

然后拿出底下两层外壳, 用铜柱及螺丝固定上, 给电池装上易拉胶(蓝色那一面先撕起来), 放上去, 同时把充电模组也放上去, 线按照下图的方式接上.
batter9

正面装上开关, 这里需要把杜邦线上的塑料头去掉, 才能通过PCB板上的洞, 通过之后, 再把塑料头装上.
batter10

背面这样连接.
batter11

然后组合起来, 把接到拨动开关的另一条线, 接到充电模块的OUT+口. 充电模块的OUT-, 接到PCB板上剩下的弯脚排针上. 左手基本上就完成了, 剩下就是把其他的外壳装上去.
batter12

组装右手的过程, 比较类似, 摇杆我装在下图的位置, 小红点, 不能直接安装到摇杆上, 我是里面塞了点东西, 然后用胶水粘上, 也可以先试试原来摇杆自带的蘑菇帽用得感觉怎么样, 觉得不行再换. 还有, 摇杆模组里的电路极右上角要剪掉一小块, 不然有个按键按不下.
battery_right1

右手的安装过程, 比较类似, 充电模块的OUT-直接用杜邦线连接到Arduino Pro Micro的随便一个GND口. 剩下就是整理线, 让外壳能合上.
battery_right2
上图的位置1和位置2合起来的时候, 会压到一起, 因为位置2是给两组VCC和GND口, 离得比较开, 可以把杜邦线的塑料头去掉, 然后用胶布封起来, 减少了一些厚度, 位置1最好不要这么做, 因为距离太近了, 而且是和锂电池直接连接的, 小心一些好.

好了, 最后就是把外壳合上, 然后用纳米双面胶把HM-10和Bluetooth HID模组粘在外壳上.

键盘做完了.

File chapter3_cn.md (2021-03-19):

# 制作左手

## 系列文章列表
* [为什么要自己做一把蓝牙机械键盘](./chapter1_cn.md)
* [用到的东西](./chapter2_cn.md)
* [制作左手](./chapter3_cn.md)
* [设置左右手蓝牙BLE](./chapter4_cn.md)
* [制作右手](./chapter5_cn.md)
* [轴体焊接及供电模块](./chapter6_cn.md)
* [后记](./chapter_tips_cn.md)

### 理论说明
怎么样让左手的Arduino Pro Micro检测到哪一行, 哪一列的按键被按下或者松开了(即状态跟之前的不一样)呢? 

我们先介绍一下主控芯片的功能.

Arduino Pro Micro这块芯片有18个IO引脚, 其中所有的IO引脚都支持输入输出数字信息(就是0和1, 输出模式可以设置高电压或者低电压, 输出高电压就相当于电源, 输入模式可以读取当前电压高低), A0-A3这几个IO引脚支持输入输出模拟信息(可以表示连续的数字, 因为像摇杆, 很难只用0和1去表示. 因为我们除了想知道有没有向右移动, 还想知道移动了多少). 其他引脚的功能参考[hookup-guide](https://learn.sparkfun.com/tutorials/pro-micro--fio-v3-hookup-guide). 

在Arduino里设置输入输出模式非常简单, 可以通过如下命令 

<pre><code>pinMode(pin, OUTPUT); //设置引脚为输出模式. 
pinMode(pin, INPUT);  //设置引脚为输入模式.
</code></pre>

因为按键相当于一个开关, 我们可以把开关两侧接到电源VCC和一个IO引脚上, IO引脚设置为输入模式, 当开关按下, 通过读取电压的高低, 我们可以知道是否被按下. 

<div align=center>


</div>

PS: 之前很好奇, 为什么仅靠一个引脚怎么能测出电压, 因为电压本质上是电势能差, 电势能和重力势能是一样的, 在位置比较高的物体(就是重力势能比较高的), 会向位置比较低的地方(重力势能比较低的地方)运动, 所以要知道电势差, 就得需要两点, 后来问了朋友, 可以简单理解成, 测的是与GND的电势差, 感兴趣可以搜索关键字"GPIO工作原理", 围观一下一个引脚里面有什么样的复杂电路.

这个想法很好, 但是有两个问题:
* 按键在没有按下的时候, 没有接到VCC电源, 这时候我们觉得IO引脚读到的电压应该低电压, 但是实际上不是这样的, IO引脚读到的是一个浮动的值, 可能是高电压, 也可能是低电压.
* 我们只有18个IO引脚, 而左手的开关(按键)有38个. 

第一个问题, 比较好解决, Arduino支持使用上拉电阻, 通过一个电阻与电源VCC相连, 固定在高电压. 从而避免这个问题. 在Arduino里使用上拉电阻的方法如下:
<pre><code> pinMode(pin, INPUT_PULLUP); //设置引脚为上拉电阻 </code></pre>
<div align=center>


</div>

如上图所示, 使用上拉电阻, 当按键按下, IO引脚能读到低电压, 因为接地GND了. 按键没有按下, 则是高电压, 因为接了电源VCC. <br>

第二个问题, 用到的解决方案叫矩阵式按键. 将键盘上的按键分成N行和M列, 用N + M个IO引脚去支持N * M个按键. 方法是先选中某一行, 其他行隐形, 然后依次判断这一行上的每一列有没有被按下.

<div align=center>


</div>
如上图所示, 引脚10和16设置成了上拉电阻模式, 此时我们选中A0引脚所在的行, 首先设置为输出模式即
<pre><code> pinMode(A0, OUTPUT);
</code></pre>
然后设置为低电压(相当于接地)即
<pre><code> digitalWrite(A0, LOW);
</code></pre>

如果此时按键A按下了, 那么16引脚所在的那一列就能读到低电压, 即使这时候按键W按下了, 因为A3是高电压所以10引脚所在的那一列也是读到高电压. 按照这种方式, 选中其中一行设置为低电压, 其他行设置为高电压, 当有按键按下时, 我们就能知道哪一行, 哪一列按下了.

但是这会引起一个叫"Ghost Key"的问题, 就是你没按那个按键, 但是却检测到这个按键被按下去了. 如下图所示, 当你同时按下QAW三个按键时, S没有按下, 但是却被认为按下了.<br>

<div align=center>


</div>
原因是从引脚10有办法连接到GND上.<br>
<div align=center>


</div>
如上图所示, 沿着绿色箭头, 引脚10能连接到GND, 使得引脚10能读到低电压, 所以这时候S被认为是按下的. 解决方案就是用二极管(就是1n4148二极管), 规定电流只能往一个方向流过, 不让反方向的电流通过. <br><br>

<div align=center>


</div>
如上图所示, 加上二极管之后, 电流就只能按照绿色箭头的方向移动, 这样引脚10的就无法和GND连接了. 

理论部分告一段落. 可以开始动手做了.

### 开始焊接左手

首先拿出一张PCB版, 和一个定位板, 因为这些都是左右手通用的, 所以不用害怕左右手弄混. 我们要把二极管焊在PCB板的背面, 因为需要保证定位板能紧紧贴合PCB板, 所以我们可以先用几个轴固定下定位板和PCB板.
left1

然后翻到反面, 把二极管焊上去, 要特别注意二极管的方向. 可以试试用电烙铁的刀头焊, 焊出来的焊点比较好看.
left2

焊完后长这样, 注意每个按键下都要焊接一个二极管.
left3

接着拿出Arduino Pro Micro, 然后安排上排针, 这里需要把RAW那个引脚的排针去掉, 因为RAW引脚用弯脚排针比较好, 方便连接到开关的杜邦线, 这个稍后处理. 

然后把左手的PCB翻到正面, 左上角已经为Arduino Pro Micro预设了位置, 上面写了ProMicro, 把Arduino Pro Micro放到上面去, 针脚放进对应的孔位.
left4

然后把正面的焊接了, 背面的先不焊.
left5

正面的焊好之后, 我们拿出一条杜邦线, 和一个弯脚排针, 只需要针, 然后放到杜邦线里.
left6

然后把这个弯脚排针放到RAW引脚对应的位置, 并用胶布固定一下. 
left7

最后翻到正面, 把原来的Arduino Pro Micro放回去, 然后把RAW引脚给焊上去.
left8

用类似的手法, 把下图里其他的位置, 也用弯脚排针焊上. 其中位置1的引脚是跟左手的HM-10进行数据交互的(上面是SDAM与HM-10的TX连接, 下面SCLM与RX连接), 位置2是给左手的HM-10供电的, 位置3是给Arduino Pro Micro供电的.
left9

左手的焊接工作, 暂时告一段落. 

解释一下, 为什么要用弯脚排针这么焊, 后面的其他地方也会用到. 弯脚排针是配合杜邦线的, 这些地方当然也可以直接用跳线, 跟对应的芯片上的引脚焊死, 这么做首先是不太好焊, 然后如果以后想升级或者想更换某些硬件, 得先去掉原来的焊点, 再重新焊, 如果只是一两处还好, 如果焊点多了的话会比较麻烦, 如果是用弯脚排针再加上杜邦线, 就免去了这个麻烦. 

(因为经验有限, 没有办法保证现在的硬件方案是正确的, 那么希望以后发现更优秀的方案时, 能够以比较小的代价去修正.)

现在可以往左手的Arduino Pro Micro里写程序了, 打开Arduino IDE, 在"示例"里找到本项目里的"left_hand", 最后点"上传"就行了.

程序烧录上去后, 用一根导线, 去模拟按键按下.
left10
然后在Arduino IDE里打开"串口监视器", 就能看到程序输出哪一行被按下, 这一行哪所有按键的状态(16进制表示).
left11
这里行和列对换了, 因为我在程序里是把一行所有按键状态发送出去了, 一个bit代表一个按键, 因为一个byte只有8个bit, 而一列不超过8个按键, 所以就把行和列对调了.

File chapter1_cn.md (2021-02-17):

# 为什么要自己做一把蓝牙机械键盘

## 系列文章列表
* [为什么要自己做一把蓝牙机械键盘](./chapter1_cn.md)
* [用到的东西](./chapter2_cn.md)
* [制作左手](./chapter3_cn.md)
* [设置左右手蓝牙BLE](./chapter4_cn.md)
* [制作右手](./chapter5_cn.md)
* [轴体焊接及供电模块](./chapter6_cn.md)
* [后记](./chapter_tips_cn.md)

下面是一系列文章, 讲怎么自己做一把蓝牙版的ergodone键盘. 

## 背景
为什么要做这样一把键盘呢？
因为我是程序员, 也是vim的使用者, 现在在用的是mac系统, 更喜欢用键盘来进行一些操作, 不喜欢把手移动到鼠标上进行一些操作, 再移到回键盘上. 除了可以用软件或者系统的快捷键, 现在很多环境下, 都有vim的插件, 比如chrome的浏览器有Vimium, zsh里有vi-mode, 文件管理可以用[ranger](https://github.com/ranger/ranger/), intellj里[IdeaVim](https://plugins.jetbrains.com/plugin/164-ideavim). Mac系统里有[vimac](https://github.com/dexterleng/vimac/), 使得用键盘操作电脑, 成为一种可能. 

当然, 比如剪视频这种工作, 必须还是有鼠标来得方便, 但是程序员的日常生活里, 这类情况比较少, 也可以用mac自带的触控板解决. 

虽然有各种vim软件插件的加持, 但是还是遇到了很难回避的问题. 单靠软件, 并不能达到我预期的效果. 所以想从硬件方面解决一些问题, 才有了自己做一把键盘的想法. 

## 强大的vim
先介绍一下我使用的vim的一些操作习惯. 

vim的学习成本很高, 学习曲线也很陡峭, 但是是一个功能非常强大的文本编辑器, 加上各种插件, 甚至可以是IDE, Markdown编辑器……

我除了写java会用intellij, 因为写java工程对代码补全要求非常高, 需要下载并且使用各种第三方依赖库. 写其他语言诸如python, javascript, html, C, C++等, 基本上都用vim. 

下面展示一些各种vim的奇技淫巧. 

### 终端下的vim

1. 记录一系列操作, 并回放, 比如下面gif显示的, 记录下我第一行的操作, 然后把这个操作, 应用到剩下的12行里. demo1

2. 使用插件[fzf](https://github.com/junegunn/fzf.vim), 加上[The Silver Searcher](https://github.com/ggreer/the_silver_searcher), 我可以方便地在项目里, 用正则表达式搜索文本, 比如我想找以KC_CAPSLOCK为结尾的某一行文本 (这也是我很想吐槽intellij的一点, 搜索字符串不太方便, 特别是在配置文件里的字符串) . 

3. 使用c.vim可以方便地编辑运行C语言, 如果能将vim的开发环境打包成docker, 上传到自己租的云服务器, 然后用ipad连接上这个云服务器, 你就可以在ipad上写点代码, 其他语言类似, 不过ipad上有一个很郁闷的地方, 一直按住backspace键, 能一直删除, 一直按住字母键, 比如j, 只会生效一次, 这就导致在ipad上不能一直按住j来不断让光标下移, 幸好有插件[vim-easymotion](https://github.com/easymotion/vim-easymotion)可以缓解这种冲突. 

### Chrome浏览器里的vimium插件

   使用插件打开超链接, 编辑当前的URL并在新标签页打开, 然后在各种标签页跳转

### Intellij里的IdeaVim插件
   使用[IdeaVim-EasyMotion](https://plugins.jetbrains.com/plugin/13360-ideavim-easymotion)快速在代码中跳转, 并且可以映射一些操作, 比如我这里使用;su来找到这个函数在哪里被调用了即ShowUsages. 

### Mac里的软件Vimac
使用[vimac](https://github.com/dexterleng/vimac/), 像浏览器里的vimium插件类似, 可以替代鼠标的一些操作. 
比如我用键盘打开intellij的File选项卡. 

### Ranger文件管理器
可以用vim类似的命令, 在终端里进行文件的各种操作. 比如可以预览一些文本文件, 图片, 视频也可以预览不过我没有配置. 可以在各种位置打tag, 在tag之间进行跳转, 比如我通过tag跳转到项目文件夹, 复制了一个文件, 然后粘贴到桌面文件夹, 然后再删除. 还有一些方便的功能, 比如批量重命名文件. 

### Zsh里的vi-mode
可以用vim类似的命令去编辑shell命令

## 还是有问题
1.  网页上可以用鼠标点击的地方, 有时候插件不能识别到. 比如DynamoDB控制台里的"项目". 这时候就得用鼠标移上去, 再点一下.  
2.  zsh可以输入一些命令的前缀, 按向上方向键, 可以搜索输入历史里, 这个前缀的命令. 这要求把手移动到方向键的位置. 当然, 可以用别的快捷键, 比如\<Ctrl-P>来替代这种情况下的向上方向键, 但是有些情况下, 其他软件并不能自定义, 并且顺手的快捷键组合有限. 

## 解决方法
### 软件
让键盘可以去移动鼠标, 比如vim的命令里, hjkl这四个按键在普通模式下, 可以用来移动光标 (在输入模式下是正常输入字母) , 借鉴这样的思想, 我们可以新建自己的模式, 这个模式下hjkl是移动鼠指针. 在另一种模式下, hjkl变成上下左右方向键. 如果是在linux下, 可以通过修改系统配置 (参考[X_keyboard_extension](https://wiki.archlinux.org/index.php/X_keyboard_extension)) , 自定义键盘布局. 如果是在mac下, 有一个神器[Karabiner-Elements](https://github.com/pqrs-org/Karabiner-Elements), 并且有别人写好的配置[rules](https://ke-complex-modifications.pqrs.org/), 你可以轻松的让键盘变成你的样子. 比如我按下CAPSLOCK, hjkl就会移动鼠标指针, 按下CAPSLOCK+SHIFT, hjkl就会是上下左右的方向键. 

但是最后的效果, 还是不让人满意, 因为我的输入法SHIFT会切换中英文, 而且不能设置左或者右SHIFT才触发这个操作, 所以用CAPSLOCK+SHIFT, 经常误触发中英文切换, 而且原来键盘上已经有很多快捷键, 想一个没有冲突的, 比较费事, 所以光靠软件, 也不能让人满意. 
### 软件加硬件
如果键盘上多了几个我可以自定义的按键, 那个上面的问题就可以解决, 同时, 我也想让自己的键盘符合一些人体工程学, 最后挑中了ergodone (是在[ergodox](https://www.ergodox.io/)的基础上改进而来, 为了节省成本) , 有两个小的键盘组成, 这样两只手可以比较自然地放下. 
并且我希望能做到如下几个方面：
* 由于ergodone是有线版本, 我希望他是蓝牙无线的, 包括左右手的连接, 右手 (当然也可以是左手) 和电脑的连接, 都是用蓝牙. 
* 能够以后方便地更换故障的部分, 或者升级部分硬件. 
* 单纯右手就是一件独立的键盘, 不需要左右手合在一起才能用
* 能够使用成熟的键盘固件, 比如tmk_keyboard
* 能够方便地更新键盘上的程序
* 能够连接上多种类型的设备, 电脑, ipad, 手机等
* 键盘上有个摇杆或者轨迹球之类的设备可以用来方便地移动鼠标指针. (可选)

需要声明的是, 我本身是偏服务器方向的程序员. 我在做这个键盘之前, 完全没有任何硬件相关的知识, 所有跟硬件相关的知识, 包括跟硬件相关的软件知识 (即嵌入式编程) , 都是从网上学的, 或者问朋友的. 所以有哪里做得不对, 麻烦不吝赐教.

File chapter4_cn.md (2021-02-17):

# 设置左右手蓝牙BLE

## 系列文章列表
* [为什么要自己做一把蓝牙机械键盘](./chapter1_cn.md)
* [用到的东西](./chapter2_cn.md)
* [制作左手](./chapter3_cn.md)
* [设置左右手蓝牙BLE](./chapter4_cn.md)
* [制作右手](./chapter5_cn.md)
* [轴体焊接及供电模块](./chapter6_cn.md)
* [后记](./chapter_tips_cn.md)

BLE跟普通蓝牙相比, 功率低, 成本低,  所以用来做左右手数据的传输.

在前一章, 我们已经把左手的PCB焊接好了, 现在我们开始设置左右手的HM-10, 让两块HM-10在上电之后, 能够自动连接, 并且左手的HM-10将数据发送给右手的HM-10(即设置主从模式). 

设置HM-10需要用串口发送AT指令. 如果你有USB转TTL的线, 并且使用的是windows系统, 那么这项工作会简单许多. 如果没有的话, 也有办法. 我们可以通过Arduino Pro Micro向HM-10发送AT指令.

首先拿出右手要用的Arduino Pro Micro, 弯脚排针, 装上排针, 插上几个杜邦线, 然后用胶带固定到下面的亚克力板上. 因为这块Arduino Pro Micro也是预计安装在这里的, 所以用这种方式焊, 可以避免最后这块凸起, 导致外壳合起来不严实. 针脚如果凸起, 可以用指甲刀剪掉一些.
ble1

焊好之后, 长这样. 
ble2

然后拿出左手的HM-10, HM-10的VCC和GND接Arduino Pro Micro的VCC和GND, 然后TXD接Arduino Pro Micro的RXD, RXD接Arduino Pro Micro的TXD. 
ble3

然后打开Arduino IDE, 找到示例里本项目里的"set_ble", 上传到Arduino Pro Micro里, 然后打开串口监视器, 就可以开始使用AT命令设置主从模式了. 输入"AT", 会返回"OK"(所有支持的指令可以去[官网](http://www.jnhuamao.cn/)上找), 输入"AT+ROLE0", 将当前这块HM-10设置为从设备, 然后放在一边. 接着拿出右手的HM-10, 按照相同的方法连接上, 输入"AT+ROLE2".
ble4

"AT+ROLE2"这个指令会自动搜索并连接信号强度最强的从设备, 根据文档"主从设备第一次连接的时候，只需要简单的放到一起即可，只要主设备记住了成功连接过的从设备，那么无论周围有多少个从设备，也不会发生误连接的情况。", 所以我们这时候把左手的HM-10上电, 两块HM-10放近些, 当两块HM-10上的红灯长亮, 就完成了主从配对.

主从配对完成后, 我们可以验证一下左手的HM-10确实给右手的HM-10发送正确的数据了. 拿出左手的PCB, 然后按照下图的方式连接. SDAM接HM-10的TXD, SCLM接HM-10的RXD, VCC和GND对应接上. 然后用USB给左手的Arduino Pro Micro供电. 这样就完成了配对.
ble5

为了验证左手的HM-10能给右手的HM-10发信息了. 打开示例本项目里的"test_ble", 上传到右手的Arduino Pro Micro里, 然后在左手PCB上用导线触发按键事件, 可以从串口监视器里看到左手传来的消息. FD开头, 接着是哪一行, 然后是行的状态(同样是16进制表示).
ble6

大功告成. 

这是很关键的一步.

这里先说一下我遇到的坑, 这里的HM-10从官方的淘宝店买最好(虽然运费最贵), 因为其他淘宝店的指令, 会和官方的不太一样, 这会导致连接不上, 指令不识别等问题. 我绕了很大一圈, 买了一条USB转TTL的线, 把自己linux的电脑装成windows, 下载windows才支持的对应串口程序去设置, 还是有问题...当然, 如果你熟悉HM-10等, 可以无识, 自己折腾.

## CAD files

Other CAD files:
cad/Bluetooth_Ergodone_without_joystick.dwg
cad/positioning_plate.dwg
cad/Bluetooth_ErgoDone_with_joystick.dwg

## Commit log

2021-02-08 update doc
    [Bluetooth_ErgoDone_with_joystick.dwg, Bluetooth_Ergodone_without_joystick.dwg, positioning_plate.dwg]
2021-02-17 把目录改成系列文章列表
2021-03-11 增加如何定制蓝牙HID的资料
    [Bluetooth_ErgoDone_with_joystick.dwg, Bluetooth_Ergodone_without_joystick.dwg, positioning_plate.dwg]
2021-03-19 增加定位板上开关位置的尺寸
    [Bluetooth_ErgoDone_with_joystick.dwg, Bluetooth_Ergodone_without_joystick.dwg, positioning_plate.dwg]
2021-03-21 update pcb github address
